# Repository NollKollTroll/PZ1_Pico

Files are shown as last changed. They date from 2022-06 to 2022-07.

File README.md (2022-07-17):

# PZ1_Pico

A version of the PZ1-system based on 65C02, Raspberry Pi Pico and 512KiB SRAM.

## General info

This is the second public release of SW and HW for the PZ1-project, now with some more bells and whistles.<br>
<br>
The system uses my simple preemptive multitasking scheduler to manage the 512KiB RAM, using 16KiB for itself and system data.<br>
The task switching does not waste many cycles. Every task gets its own stack and a full zero page, minus the 18 bytes used for OS-calls.<br>
EhBASIC is running in a separate task with 64KiB RAM. There are added basic-commands to deal with tasks and the filesystem.<br>
<br>
HW realised in the Pico:<br>
- Serial communication via a virtual USB serial port.<br>
- Serial port, 3.3V RX/TX on pin-header. Working but not used.<br>
- SID-sound is based on TinySID, emulated on the second core of the Pico and mixed at 96000Hz, no SID-filters. 10-bit PWM-output on a single pin.<br>
- IRQ-timer used by the scheduler, 16-bits.<br>
- Frame counter registers, incremented @50Hz, 16-bits.<br>
- HW/SW interfaces to filesystem operations.<br>
- 4 bank registers, 16KiB memory blocks, the scheduler handles ownership of blocks.<br>
<br>
The HW design is not the most efficient, mainly because the Pico lacks enough gpios to connect to the 65C02 and SRAM without buffers. The buffering is done with 74LVC-chips which adds complexity and lowers efficiency. The Pico and buffers are cheaper and more readily available than the faster and less complex Teensy 4.1.<br>
<br>
Running the Pico at the standard 133MHz can run the 65C02 @1MHz. Overclocking the Pico to 250MHz can run the 65C02 @2MHz, just the way I intended. Using the PIOs would probably improve the performance.

## History

I started the PZ1 project because I wanted to code 6502, build proper electronics hardware and investigate multitasking and bank-switched memory on a 6502-system. I also got back to designing proper PCBs, now in KiCad. I've done some iterations experimenting with:<br>
- 6502 emulation or a real 65C02.<br>
- Different MCUs: Teensy 4.0/4.1 / BluePill / Pico.<br>
- External SRAM, RAM/ROM inside MCU, RAM on Teensy quad-SPI.<br>
- Different sound emulation and output (PWM/I2S).<br>
- 74-series glue logic / SPLD.<br>

## Blog

The ongoing work of PZ1 in general can be followed on [my blog at hackaday.io](https://hackaday.io/project/171471-pz1-6502-laptop)

## Hardware

Use KiCad 6 to view/edit the schematics and PCB. There is also a PDF of the schematics.<br>
Gerbers to build the 4-layer PCB are generated and available in a separate folder.<br>
The Pico-socket in 3D-view of the PCB is not correct, too narrow.<br>
<br>
A proper BOM is missing but here are the main components:<br>
- 1x Raspberry Pi Pico<br>
- 1x WDC65C02<br>
- 1x AS6C4008, 512KiB SRAM<br>
- 2x 74LVC244<br>
- 1x 74LVC245<br>
- 2x 74LVC373<br>
- 2x 1x6 pin-header<br>
- 2x 1x4 pin-header<br>
- 1x 1x2 pin-header<br>
- a bunch of decoupling capacitors<br>

## Software

Use Arduino IDE with Earl Philhowers Pico board package, -O2 optimization.<br>
The 6502-sources include pre-assembled h-files in the repository. Assembling on your own requires installation of the very fine assembler [Jasm](http://kollektivet.nu/jasm/).<br>
Run the asm.sh file to create the necessary h-files, along with a bunch of debug- and info-files.<br>

## Contact

Mail: <adam.klotblixt@gmail.com>

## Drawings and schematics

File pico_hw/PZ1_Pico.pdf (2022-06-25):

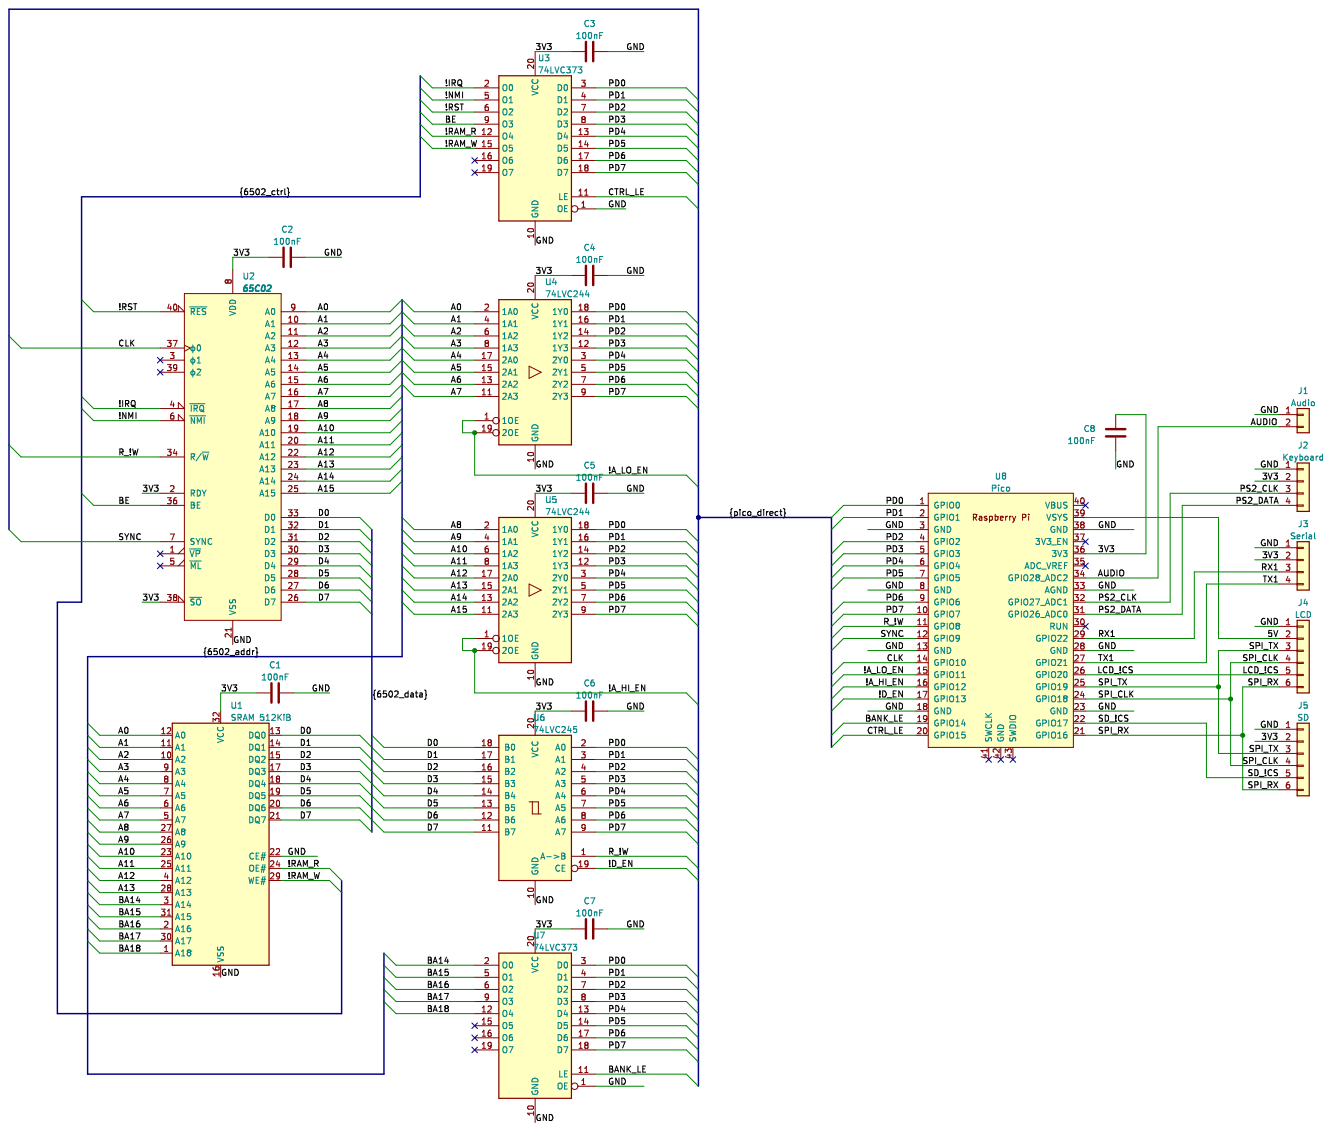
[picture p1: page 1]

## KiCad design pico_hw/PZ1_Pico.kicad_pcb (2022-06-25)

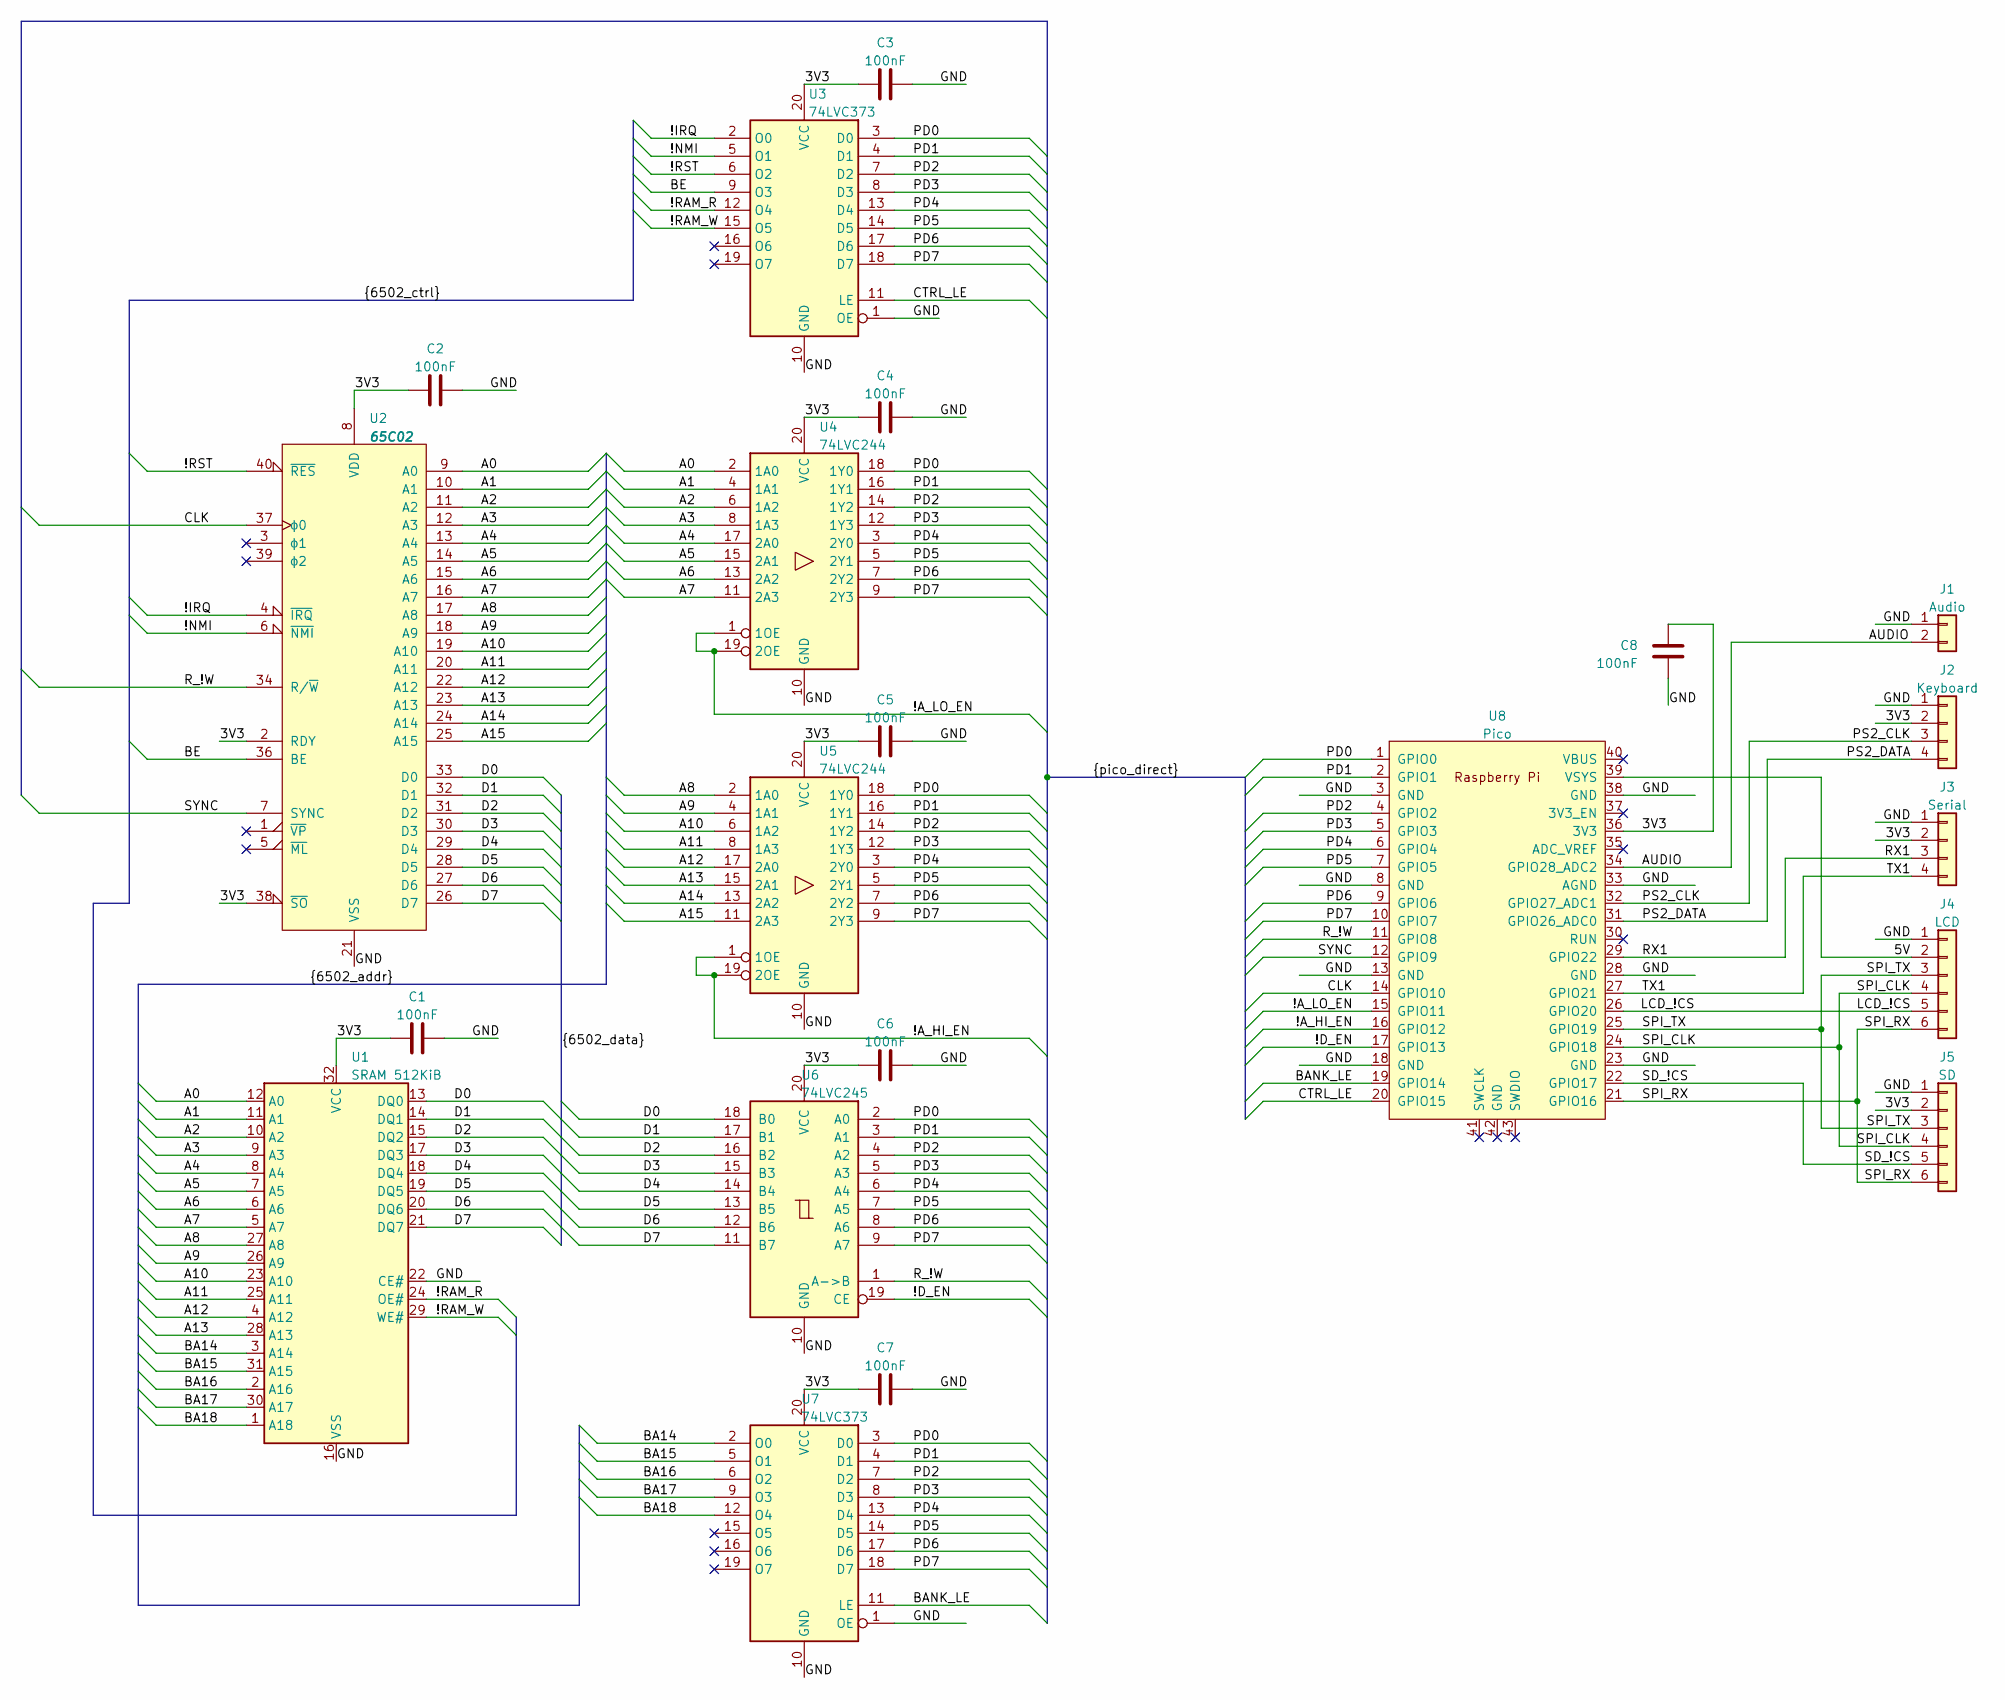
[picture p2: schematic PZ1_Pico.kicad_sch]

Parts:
C1, C2, C3, C4, C5, C6, C7, C8: 100nF; C_0805_2012Metric_Pad1.18x1.45mm_HandSolder
J1: Audio; PinHeader_1x02_P2.54mm_Vertical
J2: Keyboard; PinHeader_1x04_P2.54mm_Vertical
J3: Serial; PinHeader_1x04_P2.54mm_Vertical
J4: LCD; PinHeader_1x06_P2.54mm_Vertical
J5: SD; PinHeader_1x06_P2.54mm_Vertical
U1: SRAM 512KiB; DIP-32_W15.24mm
U2: 65C02; DIP-40_W15.24mm
U3, U7: 74LVC373; DIP-20_W7.62mm
U4, U5: 74LVC244; DIP-20_W7.62mm
U6: 74LVC245; DIP-20_W7.62mm
U8: Pico; DIP-40_W17.78mm_Socket

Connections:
/3V3: C1.1, C2.1, C3.1, C4.1, C5.1, C6.1, C7.1, C8.2, J2.2, J3.2, J5.2, U1.32 (VCC), U2.2 (RDY), U2.8 (VDD), U2.38 (~SO), U3.20 (VCC), U4.20 (VCC), U5.20 (VCC), U6.20 (VCC), U7.20 (VCC), U8.36 (3V3)
/5V: J4.2, U8.39 (VSYS)
/!A_HI_EN: U5.1 (1OE), U5.19 (2OE), U8.16 (GPIO12)
/!A_LO_EN: U4.1 (1OE), U4.19 (2OE), U8.15 (GPIO11)
/!D_EN: U6.19 (CE), U8.17 (GPIO13)
/!IRQ: U2.4 (~IRQ), U3.2 (O0)
/!NMI: U2.6 (~NMI), U3.5 (O1)
/!RAM_R: U1.24 (OE#), U3.12 (O4)
/!RAM_W: U1.29 (WE#), U3.15 (O5)
/!RST: U2.40 (~RES), U3.6 (O2)
/A0: U1.12 (A0), U2.9 (A0), U4.2 (1A0)
/A1: U1.11 (A1), U2.10 (A1), U4.4 (1A1)
/A2: U1.10 (A2), U2.11 (A2), U4.6 (1A2)
/A3: U1.9 (A3), U2.12 (A3), U4.8 (1A3)
/A4: U1.8 (A4), U2.13 (A4), U4.17 (2A0)
/A5: U1.7 (A5), U2.14 (A5), U4.15 (2A1)
/A6: U1.6 (A6), U2.15 (A6), U4.13 (2A2)
/A7: U1.5 (A7), U2.16 (A7), U4.11 (2A3)
/A8: U1.27 (A8), U2.17 (A8), U5.2 (1A0)
/A9: U1.26 (A9), U2.18 (A9), U5.4 (1A1)
/A10: U1.23 (A10), U2.19 (A10), U5.6 (1A2)
/A11: U1.25 (A11), U2.20 (A11), U5.8 (1A3)
/A12: U1.4 (A12), U2.22 (A12), U5.17 (2A0)
/A13: U1.28 (A13), U2.23 (A13), U5.15 (2A1)
/A14: U2.24 (A14), U5.13 (2A2)
/A15: U2.25 (A15), U5.11 (2A3)
/AUDIO: J1.2, U8.34 (GPIO28_ADC2)
/BA14: U1.3 (A14), U7.2 (O0)
/BA15: U1.31 (A15), U7.5 (O1)
/BA16: U1.2 (A16), U7.6 (O2)
/BA17: U1.30 (A17), U7.9 (O3)
/BA18: U1.1 (A18), U7.12 (O4)
/BANK_LE: U7.11 (LE), U8.19 (GPIO14)
/BE: U2.36 (BE), U3.9 (O3)
/CLK: U2.37 (ϕ0), U8.14 (GPIO10)
/CTRL_LE: U3.11 (LE), U8.20 (GPIO15)
/D0: U1.13 (DQ0), U2.33 (D0), U6.18 (B0)
/D1: U1.14 (DQ1), U2.32 (D1), U6.17 (B1)
/D2: U1.15 (DQ2), U2.31 (D2), U6.16 (B2)
/D3: U1.17 (DQ3), U2.30 (D3), U6.15 (B3)
/D4: U1.18 (DQ4), U2.29 (D4), U6.14 (B4)
/D5: U1.19 (DQ5), U2.28 (D5), U6.13 (B5)
/D6: U1.20 (DQ6), U2.27 (D6), U6.12 (B6)
/D7: U1.21 (DQ7), U2.26 (D7), U6.11 (B7)
/GND: C1.2, C2.2, C3.2, C4.2, C5.2, C6.2, C7.2, C8.1, J1.1, J2.1, J3.1, J4.1, J5.1, U1.16 (VSS), U1.22 (CE#), U2.21 (VSS), U3.1 (OE), U3.10 (GND), U4.10 (GND), U5.10 (GND), U6.10 (GND), U7.1 (OE), U7.10 (GND), U8.3 (GND), U8.8 (GND), U8.13 (GND), U8.18 (GND), U8.23 (GND), U8.28 (GND), U8.33 (AGND), U8.38 (GND)
/LCD_!CS: J4.5, U8.26 (GPIO20)
/PD0: U3.3 (D0), U4.18 (1Y0), U5.18 (1Y0), U6.2 (A0), U7.3 (D0), U8.1 (GPIO0)
/PD1: U3.4 (D1), U4.16 (1Y1), U5.16 (1Y1), U6.3 (A1), U7.4 (D1), U8.2 (GPIO1)
/PD2: U3.7 (D2), U4.14 (1Y2), U5.14 (1Y2), U6.4 (A2), U7.7 (D2), U8.4 (GPIO2)
/PD3: U3.8 (D3), U4.12 (1Y3), U5.12 (1Y3), U6.5 (A3), U7.8 (D3), U8.5 (GPIO3)
/PD4: U3.13 (D4), U4.3 (2Y0), U5.3 (2Y0), U6.6 (A4), U7.13 (D4), U8.6 (GPIO4)
/PD5: U3.14 (D5), U4.5 (2Y1), U5.5 (2Y1), U6.7 (A5), U7.14 (D5), U8.7 (GPIO5)
/PD6: U3.17 (D6), U4.7 (2Y2), U5.7 (2Y2), U6.8 (A6), U7.17 (D6), U8.9 (GPIO6)
/PD7: U3.18 (D7), U4.9 (2Y3), U5.9 (2Y3), U6.9 (A7), U7.18 (D7), U8.10 (GPIO7)
/PS2_CLK: J2.3, U8.32 (GPIO27_ADC1)
/PS2_DATA: J2.4, U8.31 (GPIO26_ADC0)
/RX1: J3.3, U8.29 (GPIO22)
/R_!W: U2.34 (R/~W), U6.1 (A->B), U8.11 (GPIO8)
/SD_!CS: J5.5, U8.22 (GPIO17)
/SPI_CLK: J4.4, J5.4, U8.24 (GPIO18)
/SPI_RX: J4.6, J5.6, U8.21 (GPIO16)
/SPI_TX: J4.3, J5.3, U8.25 (GPIO19)
/SYNC: U2.7 (SYNC), U8.12 (GPIO9)
/TX1: J3.4, U8.27 (GPIO21)

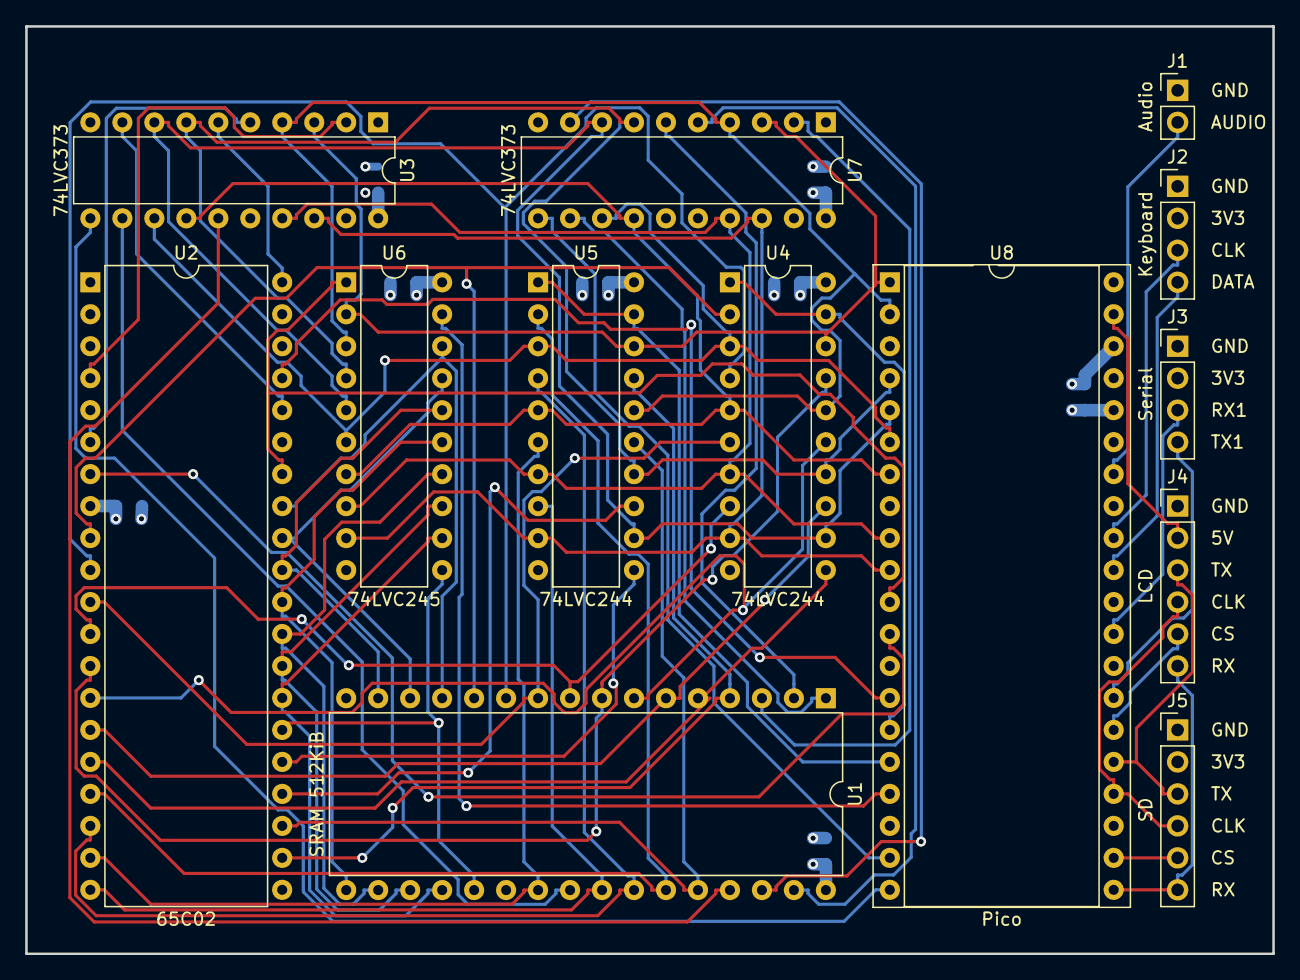
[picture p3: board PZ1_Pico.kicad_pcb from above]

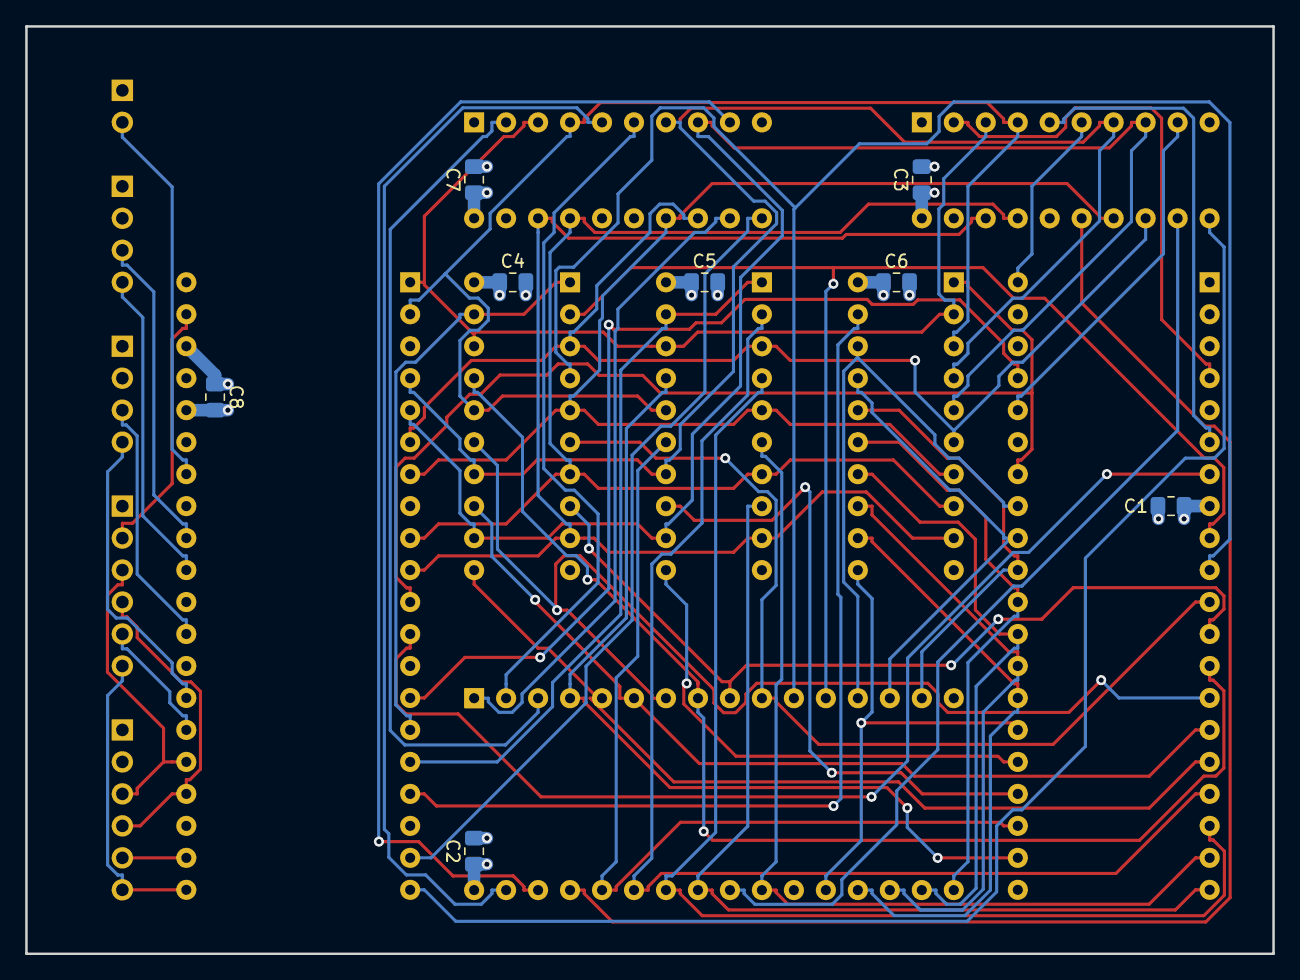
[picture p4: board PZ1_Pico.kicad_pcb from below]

Board: 4 copper layers, 99.1 x 73.7 mm, 21 parts (8 on the bottom side), 64 nets.

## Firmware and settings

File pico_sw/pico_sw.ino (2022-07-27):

/*
Written in 2022 by Adam Klotblixt (adam.klotblixt@gmail.com)

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
You should have received a copy of the CC0 Public Domain Dedication
along with this software. If not, see
<http://creativecommons.org/publicdomain/zero/1.0/>.
*/

/*
Best compiled with -O2 optimization,
timings are tested to work at 133 & 250MHz
*/
//#define PICO_250_MHZ

#define SER_DEBUG
#define SerDebug Serial    
//SerialPIO Ser6502(21, 22, 32);
#define Ser6502 Serial

#include "hardware/pwm.h"
#include "hardware/gpio.h"
#include "hardware/irq.h"

#include <SD.h>

#include "lowLevel.h"
#include "irqTimer.h"
#include "sid.h"
#include "pwmAudio.h" 
#include "fileSystem.h"

#include "6502-src/ehbasic.h"
#include "6502-src/scheduler.h"

void setup() 
{
    pinMode(PD0,       OUTPUT);
    pinMode(PD1,       OUTPUT);
    pinMode(PD2,       OUTPUT);
    pinMode(PD3,       OUTPUT);
    pinMode(PD4,       OUTPUT);
    pinMode(PD5,       OUTPUT);
    pinMode(PD6,       OUTPUT);
    pinMode(PD7,       OUTPUT);
    pinMode(RW,        INPUT);
    pinMode(SYNC,      INPUT);
    pinMode(CLK,       OUTPUT);
    pinMode(A_LO_EN_N, OUTPUT);
    pinMode(A_HI_EN_N, OUTPUT);
    pinMode(D_EN_N,    OUTPUT);
    pinMode(BANK_LE,   OUTPUT);
    pinMode(CTRL_LE,   OUTPUT);
    
    pinMode(SD_CS_N,      OUTPUT);  
    digitalWrite(SD_CS_N, HIGH);
    
    digitalWrite(CLK,       HIGH);
    digitalWrite(A_LO_EN_N, HIGH);
    digitalWrite(A_HI_EN_N, HIGH);
    digitalWrite(D_EN_N,    HIGH);
    digitalWrite(BANK_LE,   LOW);
    digitalWrite(CTRL_LE,   LOW);

    ctrlValue = 255 & ~CTRL_RST_N;
    setCtrl(ctrlValue);

    Ser6502.begin(115200);
    SerDebug.begin(115200);
    while(!Serial)
    {
    }

    reset6502();
    irqTimerInit();  
    fsInit();    
    
    frameCounter = 0;    
    frameTimer = time_us_32() + FRAME_TIME_US;    
}

void loop() 
{  
    uint16_t cpuAddr;
    uint8_t cpuData;

    //sync with next frame start
    while (time_us_32() < frameTimer)
    {
    }

    //run 65C02 for one frame
    for (int frameCycles = 0; frameCycles < (CPU_FREQUENCY / FRAME_RATE); frameCycles++)
    {   
        //CLK is LOW here
        cpuAddr = getAddr();  
        uint8_t activeBlock = portMem6502[(cpuAddr >> 14) + (PORT_BANK_0 & 0xFF)];
        setBank(activeBlock);
        gpio_put(CLK, HIGH);
        
        if (gpio_get(RW) == HIGH)
        {   //read operation          
            if (cpuAddr <= 0xFDFF) 
            {   //banked memory 0x0000-0xFDFF
                if (activeBlock <= 127)
                {   //blocks 0-127 are RAM
                    setCtrlFast(ctrlValue & ~CTRL_RAM_R_N);
                    wait1();
                    #ifdef PICO_250_MHZ
                    wait1();
                    wait1();
                    #endif
                    gpio_put(CLK, LOW);
                    setCtrlFast(ctrlValue);
                }
                else if (activeBlock == 254)
                {   //block 254 is EhBasic in ROM
                    cpuData = ehbasic_bin[cpuAddr & 0x3FFF];
                    setDataAndClk(cpuData);
                }
                else
                {   //block 255 is scheduler/boot ROM
                    //blocks 128-253 are unused, mirrored scheduler ROM
                    cpuData = scheduler_bin[cpuAddr & 0x3FFF];
                    setDataAndClk(cpuData);
                }
            }
            else if (cpuAddr <= 0xFEFF) 
            {   //I/O-device read at 0xFE00-0xFEFF               
                switch (cpuAddr) 
                {   //take action depending on device
                    // ******** SID registers ********                
                    case PORT_SID_00:
                    case PORT_SID_01:
                    case PORT_SID_02:
                    case PORT_SID_03:
                    case PORT_SID_04:
                    case PORT_SID_05:
                    case PORT_SID_06:
                    case PORT_SID_07:
                    case PORT_SID_08:
                    case PORT_SID_09:
                    case PORT_SID_0A:
                    case PORT_SID_0B:
                    case PORT_SID_0C:
                    case PORT_SID_0D:
                    case PORT_SID_0E:
                    case PORT_SID_0F:
                    case PORT_SID_10:
                    case PORT_SID_11:
                    case PORT_SID_12:
                    case PORT_SID_13:
                    case PORT_SID_14:
                    case PORT_SID_15:
                    case PORT_SID_16:
                    case PORT_SID_17:
                    case PORT_SID_18:
                    case PORT_SID_19:
                    case PORT_SID_1A:
                    case PORT_SID_1B:
                    case PORT_SID_1C:
                    {
                        cpuData = sid_read(cpuAddr & 0x1F);
                        setDataAndClk(cpuData);
                        break;
                    }
                    // ******** Memory bank registers ********
                        // Same as default
                    // ******** Serial port registers ********
                    case PORT_SERIAL_0_IN: 
                    {
                        if (Ser6502.available()) 
                        {
                            cpuData = Ser6502.read();
                        }
                        else 
                        {
                            cpuData = 0;
                        }
                        setDataAndClk(cpuData);
                        break;
                    }
                    case PORT_SERIAL_0_FLAGS:
                    {
                        if (Ser6502.available()) 
                        {
                            cpuData = 64;
                        }
                        else 
                        {
                            cpuData = 0;
                        }
                        setDataAndClk(cpuData);
                        break;
                    }
                    // ******** Frame counter registers********
                    case PORT_FRAME_COUNTER_LO: 
                    {
                        cpuData = frameCounter & 255;
                        setDataAndClk(cpuData);
                        break;
                    }
                    case PORT_FRAME_COUNTER_HI: 
                    {
                        cpuData = frameCounter >> 8;
                        setDataAndClk(cpuData);
                        break;
                    }
                    // ******** File system registers ********
                    case PORT_FILE_DATA: 
                    {
                        cpuData = fsDataRead();
                        setDataAndClk(cpuData);
                        break;
                    }
                    case PORT_FILE_STATUS: 
                    {
                        cpuData = (uint8_t)fileStatus;
                        setDataAndClk(cpuData);
                        break;
                    }
                    // ******** Irq timer registers ********
                        // Same as default
                    // ******** All other I/O ********
                    default: 
                    {
                        cpuData = portMem6502[cpuAddr & 0xFF];
                        setDataAndClk(cpuData);
                        break;
                    }
                }
            }
            else 
            {   //top page ROM read at 0xFF00-0xFFFF, regardless of BANK_3                
                cpuData = scheduler_bin[0x3F00 + (cpuAddr & 0xFF)];
                setDataAndClk(cpuData);
            }
        }
        else
        {   //write operation
            if (cpuAddr <= 0xFDFF)
            {   //banked memory 0x0000-0xFDFF
                if (activeBlock <= 127)
                {   //banks 0-127 are RAM
                    setCtrlFast(ctrlValue & ~CTRL_RAM_W_N);
                    setCtrlFast(ctrlValue);
                    gpio_put(CLK, LOW);
                }
                else
                {   //banks 128-255 are ROM
                    //Writing to ROM? Nope.
                    gpio_put(CLK, LOW);
                }
            }
            else if (cpuAddr <= 0xFEFF)
            {   //I/O-device write at 0xFE00-0xFEFF
                cpuData = getData();
                portMem6502[cpuAddr & 0xFF] = cpuData;                
                switch (cpuAddr)
                {   //take action depending on device
                    //******** SID registers ********
                    case PORT_SID_00: 
                    case PORT_SID_01: 
                    case PORT_SID_02: 
                    case PORT_SID_03: 
                    case PORT_SID_04: 
                    case PORT_SID_05: 
                    case PORT_SID_06: 
                    case PORT_SID_07: 
                    case PORT_SID_08: 
                    case PORT_SID_09: 
                    case PORT_SID_0A: 
                    case PORT_SID_0B: 
                    case PORT_SID_0C: 
                    case PORT_SID_0D: 
                    case PORT_SID_0E: 
                    case PORT_SID_0F: 
                    case PORT_SID_10: 
                    case PORT_SID_11: 
                    case PORT_SID_12: 
                    case PORT_SID_13: 
                    case PORT_SID_14: 
                    case PORT_SID_15: 
                    case PORT_SID_16: 
                    case PORT_SID_17: 
                    case PORT_SID_18: 
                    case PORT_SID_19: 
                    case PORT_SID_1A: 
                    case PORT_SID_1B: 
                    case PORT_SID_1C:
                    {
                        sid_write(cpuAddr & 0x1F, cpuData);
                        gpio_put(CLK, LOW);
                        break;
                    }
                    // ******** Memory bank registers ********
                        // Same as default
                    // ******** Serial port registers ********
                    case PORT_SERIAL_0_OUT:
                    {
                        Ser6502.write(cpuData);
                        gpio_put(CLK, LOW);
                        break;
                    }       
                    // ******** Frame counter registers ********
                        // Same as default
                    // ******** File system registers ********
                    case PORT_FILE_CMD:
                    {
                        fsCmdWrite(cpuData);
                        gpio_put(CLK, LOW);
                        break;
                    }
                    case PORT_FILE_DATA:
                    {
                        fsDataWrite(cpuData);
                        gpio_put(CLK, LOW);
                        break;
                    }
                    // ******** Irq timer registers ********
                    case PORT_IRQ_TIMER_LO:
                    {   //target lo
                        irqTimerWriteLo(cpuData);
                        gpio_put(CLK, LOW);
                        break;
                    }
                    case PORT_IRQ_TIMER_HI:
                    {   //target hi
                        irqTimerWriteHi(cpuData);
                        gpio_put(CLK, LOW);
                        break;
                    }
                    case PORT_IRQ_TIMER_RESET:
                    {  
                        irqTimerReset();
                        gpio_put(CLK, LOW);
                        break;
                    }
                    case PORT_IRQ_TIMER_TRIG: 
                    {
                        irqTimerTrig();
                        gpio_put(CLK, LOW);
                        break;
                    }
                    case PORT_IRQ_TIMER_PAUSE: 
                    {
                        irqTimerPause();
                        gpio_put(CLK, LOW);
                        break;
                    }
                    case PORT_IRQ_TIMER_CONT:
                    {
                        irqTimerCont();
                        gpio_put(CLK, LOW);
                        break;
                    }
                    // ******** Default ********
                    default: 
                    {   //nothing more to do, already written cpuData to portMem6502
                        gpio_put(CLK, LOW);
                        break;
                    }
                }
            }
            else 
            {   //top page ROM write at 0xFF00-0xFFFF, regardless of BANK_3                
                //Writing to ROM? Nope.
                gpio_put(CLK, LOW);
            }
        }
        //update the timer every CPU-cycle
        irqTimerTick();
    }
    
    if (time_us_32() >= (frameTimer + FRAME_TIME_US))
    {   //frame took too long, skip an extra frame to catch up        
        #ifdef SER_DEBUG        
        SerDebug.print("\t\t\t!!! ");
        SerDebug.println(time_us_32() - frameTimer);
        #endif
        frameTimer += FRAME_TIME_US;
        frameCounter++;
    }
    #ifdef SER_DEBUG        
    else if(frameCounter % 50 == 0)
    {   //every 50th frame, print how many us the last frame took
        SerDebug.print("\t\t ");
        SerDebug.println(time_us_32() - frameTimer);
    }
    #endif

    frameTimer += FRAME_TIME_US;
    frameCounter++;
}

void setup1()
{
    sid_reset(SAMPLE_RATE);
    pwmInit(SAMPLE_RATE);
}

void loop1()
{
}

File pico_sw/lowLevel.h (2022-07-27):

/*
Written in 2022 by Adam Klotblixt (adam.klotblixt@gmail.com)

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
You should have received a copy of the CC0 Public Domain Dedication
along with this software. If not, see
<http://creativecommons.org/publicdomain/zero/1.0/>.
*/

#ifndef LOWLEVEL_H
#define LOWLEVEL_H

// system characteristics
#define CPU_FREQUENCY  1000000 //Hz
#define FRAME_RATE     50 //Hz
#define FRAME_TIME_US  (1000000 / FRAME_RATE)
#define SAMPLE_RATE    96000 //Hz

// SID registers
#define PORT_SID_00           0xFE00
#define PORT_SID_01           0xFE01
#define PORT_SID_02           0xFE02
#define PORT_SID_03           0xFE03
#define PORT_SID_04           0xFE04
#define PORT_SID_05           0xFE05
#define PORT_SID_06           0xFE06
#define PORT_SID_07           0xFE07
#define PORT_SID_08           0xFE08
#define PORT_SID_09           0xFE09
#define PORT_SID_0A           0xFE0A
#define PORT_SID_0B           0xFE0B
#define PORT_SID_0C           0xFE0C
#define PORT_SID_0D           0xFE0D
#define PORT_SID_0E           0xFE0E
#define PORT_SID_0F           0xFE0F
#define PORT_SID_10           0xFE10
#define PORT_SID_11           0xFE11
#define PORT_SID_12           0xFE12
#define PORT_SID_13           0xFE13
#define PORT_SID_14           0xFE14
#define PORT_SID_15           0xFE15
#define PORT_SID_16           0xFE16
#define PORT_SID_17           0xFE17
#define PORT_SID_18           0xFE18
#define PORT_SID_19           0xFE19
#define PORT_SID_1A           0xFE1A
#define PORT_SID_1B           0xFE1B
#define PORT_SID_1C           0xFE1C
// bank registers
#define PORT_BANK_0           0xFE20
#define PORT_BANK_1           0xFE21
#define PORT_BANK_2           0xFE22
#define PORT_BANK_3           0xFE23
// serial port registers
#define PORT_SERIAL_0_FLAGS   0xFE30 //bit 7: out-buffer full, bit 6: in-data available
#define PORT_SERIAL_0_IN      0xFE31
#define PORT_SERIAL_0_OUT     0xFE32
// frame counter registers
#define PORT_FRAME_COUNTER_LO 0xFE40
#define PORT_FRAME_COUNTER_HI 0xFE41
// file system registers
#define PORT_FILE_CMD         0xFE60
#define PORT_FILE_DATA        0xFE61
#define PORT_FILE_STATUS      0xFE62
// IRQ timer port registers
#define PORT_IRQ_TIMER_LO     0xFE80  //writing the lo-value fills the intermediate register
#define PORT_IRQ_TIMER_HI     0xFE81  //writing the hi-value sets the timer from the completed intermediate register
#define PORT_IRQ_TIMER_RESET  0xFE82  //timer = 0 so it can count a full cycle again
#define PORT_IRQ_TIMER_TRIG   0xFE83  //timer = max timer-value, so it triggers an irq
#define PORT_IRQ_TIMER_PAUSE  0xFE84  //pause the timer indefinitely
#define PORT_IRQ_TIMER_CONT   0xFE85  //continue the timer after a pause, also acks a triggered timer
uint8_t portMem6502[256];

// pin definitions
#define PD0            0
#define PD1            1
#define PD2            2
#define PD3            3
#define PD4            4
#define PD5            5
#define PD6            6
#define PD7            7
#define RW             8
#define SYNC           9
#define CLK            10
#define A_LO_EN_N      11
#define A_HI_EN_N      12
#define D_EN_N         13
#define BANK_LE        14
#define CTRL_LE        15
#define SPI_RX         16
#define SD_CS_N        17
#define SPI_CLK        18
#define SPI_TX         19
#define LCD_CS_N       20
#define LED_PIN        25
#define AUDIO_PIN      28
// ctrl-port
#define CTRL_IRQ_N     1
#define CTRL_NMI_N     2
#define CTRL_RST_N     4
#define CTRL_BE        8
#define CTRL_RAM_R_N   16
#define CTRL_RAM_W_N   32
uint8_t ctrlValue;

int32_t frameTimer;
uint16_t frameCounter;

#define wait1() gpio_get(LED_PIN)

static inline void setBank(uint8_t value) 
{
    gpio_set_dir_out_masked(255);
    gpio_put_masked(255, value);
    gpio_put(BANK_LE, HIGH);
    gpio_put(BANK_LE, LOW);  
}

static inline void setCtrl(uint8_t value) 
{
    gpio_set_dir_out_masked(255);
    gpio_put_masked(255, value);
    gpio_put(CTRL_LE, HIGH);
    gpio_put(CTRL_LE, LOW);  
}

static inline void setCtrlFast(uint8_t value) 
{   //WARNING: only use if the pins are already outputs, to save some time
    //gpio_set_dir_out_masked(255);
    gpio_put_masked(255, value);
    gpio_put(CTRL_LE, HIGH);
    gpio_put(CTRL_LE, LOW);   
}

static inline uint16_t getAddr() 
{
    uint16_t value;
    gpio_set_dir_in_masked(255);
    gpio_put(A_HI_EN_N, LOW);
    wait1();
    wait1();
    wait1();
    #ifdef PICO_250_MHZ
    wait1();
    #endif
    value = (gpio_get_all() & 255) << 8;
    gpio_put(A_HI_EN_N, HIGH);      
    gpio_put(A_LO_EN_N, LOW);
    wait1();
    wait1();
    wait1();
    #ifdef PICO_250_MHZ
    wait1();
    #endif
    value = value | (gpio_get_all() & 255);
    gpio_put(A_LO_EN_N, HIGH);      
    return value;
}

static inline uint8_t getData() 
{
    uint8_t value;    
    gpio_set_dir_in_masked(255);
    gpio_put(D_EN_N, LOW);
    wait1();
    wait1();
    wait1();
    #ifdef PICO_250_MHZ
    wait1();
    #endif
    value = gpio_get_all() & 255;
    gpio_put(D_EN_N, HIGH);  
    return value;
}

static inline void setDataAndClk(uint8_t value) 
{
    gpio_set_dir_out_masked(255);
    gpio_put_masked(255, value);
    gpio_put(D_EN_N, LOW);
    #ifdef PICO_250_MHZ
    wait1();
    #endif
    gpio_put(CLK, LOW);    
    gpio_put(D_EN_N, HIGH);
}

void reset6502() 
{
    ctrlValue = 255 & ~CTRL_RST_N;
    setCtrl(ctrlValue);
    busy_wait_us_32(1);
    for (int i = 0; i < 16; i++)
    {
        gpio_put(CLK, HIGH);
        busy_wait_us_32(1);
        gpio_put(CLK, LOW);
        busy_wait_us_32(1);
    }
    ctrlValue = ctrlValue | CTRL_RST_N;
    setCtrl(ctrlValue);
}

#endif //LOWLEVEL_H

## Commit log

2022-06-25 First public release, as simple as possible
    [PZ1_Pico-B_Cu.gbl, PZ1_Pico-B_Mask.gbs, PZ1_Pico-B_Paste.gbp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]
2022-06-26 Added SID, IRQ-timer, frameCounter. Cleaned up low level stuff. Can run 133MHz or 250MHz.
2022-07-15 Mega-update for threaded scheduler and EhBasic, lots of new HW.
    [PZ1_Pico-B_Cu.gbl, PZ1_Pico-B_Mask.gbs, PZ1_Pico-B_Paste.gbp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]
2022-07-16 Fixing timings for 133/250 MHz
    [lowLevel.h, pico_sw.ino]
2022-07-27 Moved HW-related files to separate folder.
    [PZ1_Pico-B_Cu.gbl, PZ1_Pico-B_Mask.gbs, PZ1_Pico-B_Paste.gbp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]

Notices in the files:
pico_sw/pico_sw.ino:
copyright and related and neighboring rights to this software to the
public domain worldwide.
